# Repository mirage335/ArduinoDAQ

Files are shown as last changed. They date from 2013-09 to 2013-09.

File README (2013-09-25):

Copyright (C) 2013 mirage335
See the end of the file for license conditions.
See license.txt for USB_DAQ license conditions.

__Usage__
High-precision, low sample rate (<3kHz), DC coupled USB analog converter. Essentially a "sound card" suitable for biosignal applications (EEG), digital radios, optical sensors, hobby electronics, and other high dynamic range measurements.

BNC Connector accepts +/-8Vin. USB outputs the value according to a sample rate and format specified in firmware, by default, 100Hz @ S32_LE. LED indicator idenfities healthy startup and input overload.

__Firmware__
In the arduino IDE, set Tools --> Board --> Arduino Leonardo . Using an AVR programmer (eg. https://www.sparkfun.com/products/9825 ), either upload the leonardo bootloader or the sketch. Uploading the bootloader allows programming and serial debugging directly over USB.

__Design__
The LTC2440's input range includes floating voltages from 0.5*Vcc to -0.5Vcc. However, ESD protection circuitry rejects inputs referenced to, and below, other grounds on the chip. Carefully designed low-noise biasing circuitry negates this problem.

Board layout is critical. Neighboring digital cirucits introudce high-amplitude high-frequency noise, which is then subject to stray rectification in analog circuits. Further, the LTC2440's switched capacitor inputs introduce high frequency noise, requiring immediate decoupling.

Firmware includes code for sharp, highly efficient IIR low pass filtering. High-frequency noise may be greatly reduced with little effect on the passband.

USA companies provide all parts in these schematics.

__Safety__
USB ports are typically unfused (despite specifications to the contrary). Better to preform smoke testing with a USB wall charger, rather than an expensive computer.

Device does not offer line isolation.

_Testing_
This particular version improves noise problems encountered with the previous version. A previous version was operational, 

__Copyright__
This file is part of USB_DAQ.

USB_DAQ is free software: you can redistribute it and/or modify
it under the terms of the GNU General Public License as published by
the Free Software Foundation, either version 3 of the License, or
(at your option) any later version.

USB_DAQ is distributed in the hope that it will be useful,
but WITHOUT ANY WARRANTY; without even the implied warranty of
MERCHANTABILITY or FITNESS FOR A PARTICULAR PURPOSE.  See the
GNU General Public License for more details.

You should have received a copy of the GNU General Public License
along with USB_DAQ.  If not, see <http://www.gnu.org/licenses/>.

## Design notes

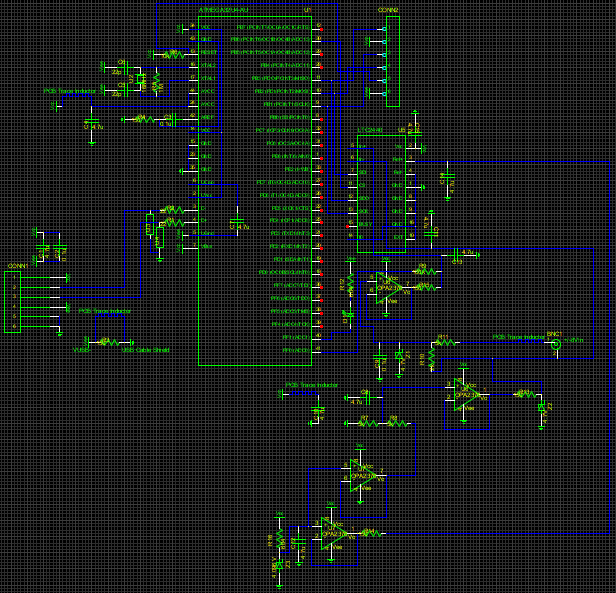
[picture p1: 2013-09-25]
USB_DAQ.sch.png

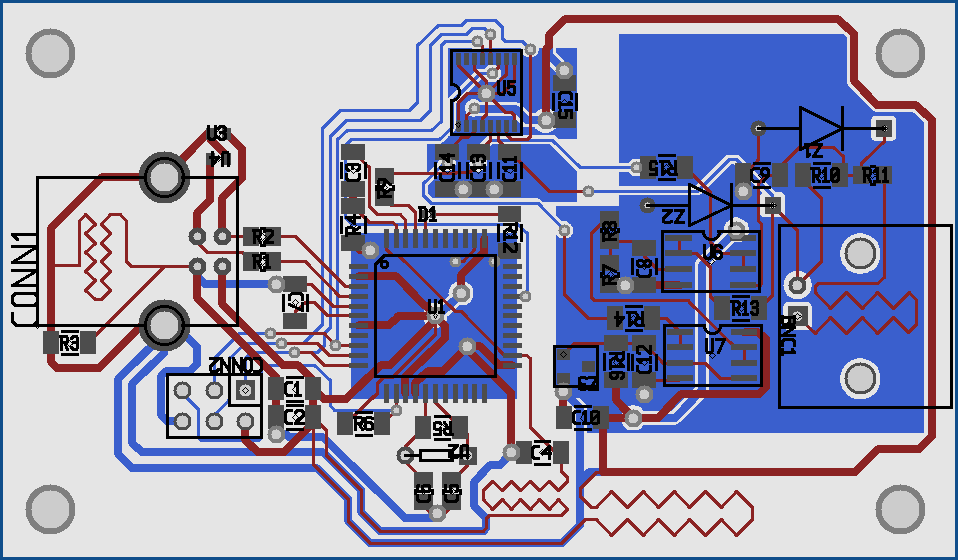
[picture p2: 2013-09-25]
USB_DAQ.pcb.png

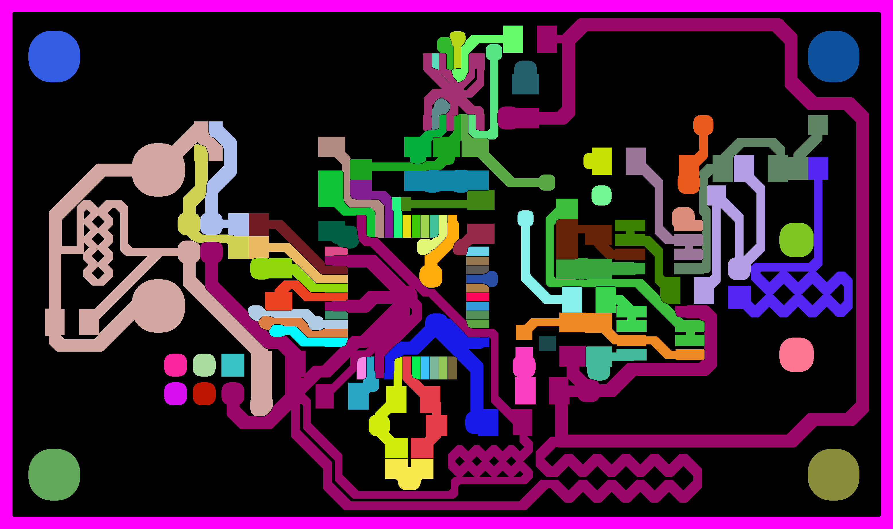
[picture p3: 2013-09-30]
hacdcCNC/USB_DAQ/outp7_traced.png

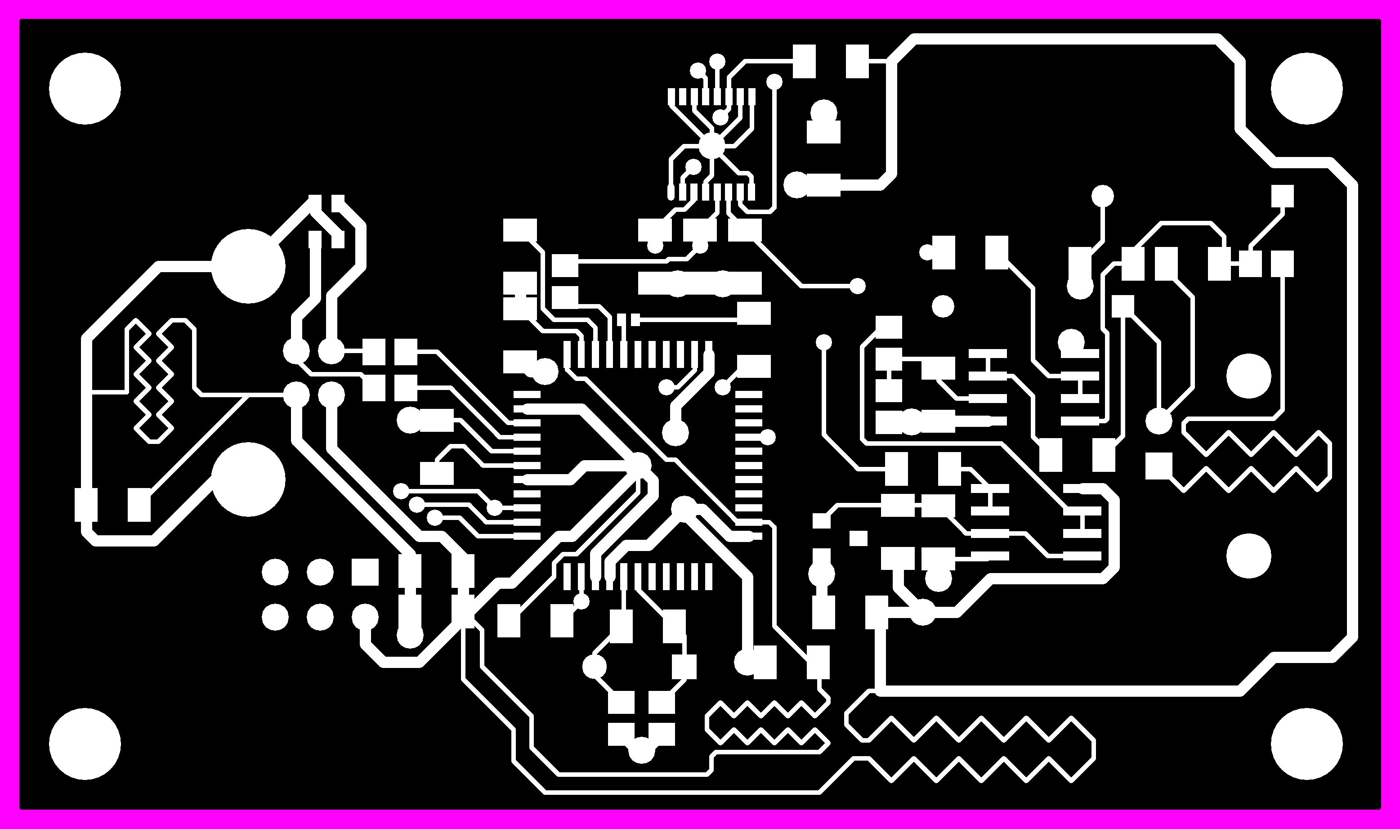
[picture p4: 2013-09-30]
hacdcCNC/USB_DAQ/outp5_masked.png

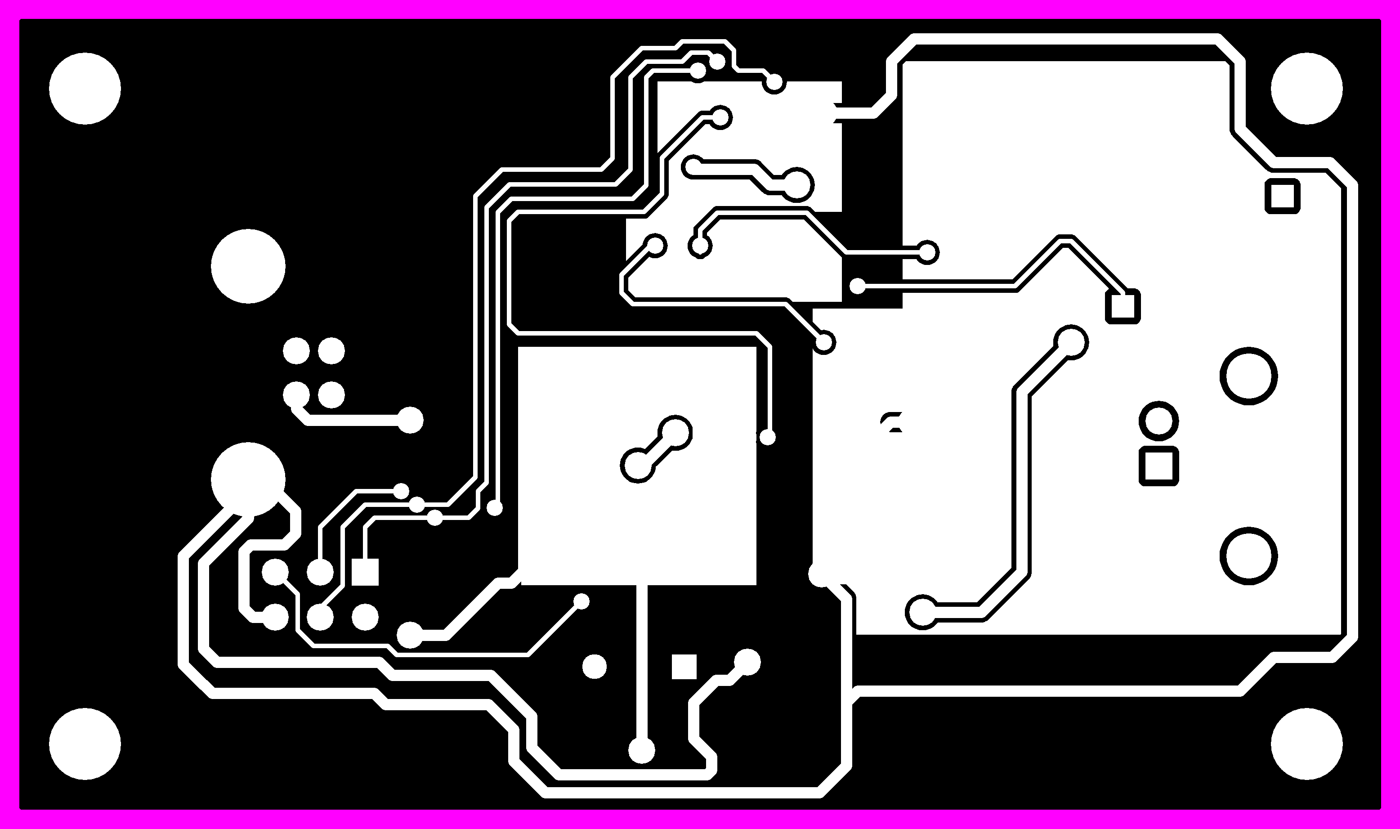
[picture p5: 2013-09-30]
hacdcCNC/USB_DAQ/outp4_masked.png

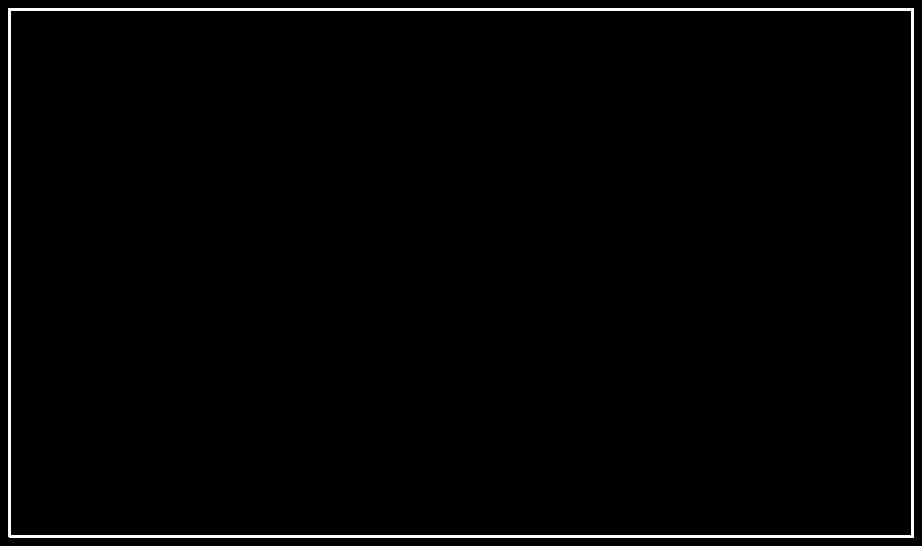
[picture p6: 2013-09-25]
hacdcCNC/USB_DAQ/outp2_original_outline.png

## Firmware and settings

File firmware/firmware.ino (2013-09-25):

/*
The MIT License (MIT)

Copyright (c) 2013 mirage335

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
THE SOFTWARE IS PROVIDED "AS IS", WITHOUT WARRANTY OF ANY KIND, EXPRESS OR
IMPLIED, INCLUDING BUT NOT LIMITED TO THE WARRANTIES OF MERCHANTABILITY,
FITNESS FOR A PARTICULAR PURPOSE AND NONINFRINGEMENT. IN NO EVENT SHALL THE
AUTHORS OR COPYRIGHT HOLDERS BE LIABLE FOR ANY CLAIM, DAMAGES OR OTHER
LIABILITY, WHETHER IN AN ACTION OF CONTRACT, TORT OR OTHERWISE, ARISING FROM,
OUT OF OR IN CONNECTION WITH THE SOFTWARE OR THE USE OR OTHER DEALINGS IN
THE SOFTWARE.
*/

/*
http://mirage335-site.dyndns.org
*/

/*
Credits:
Original example, "Interface between Arduino DM board and Linear Tech LTC2440 24-bit ADC Nov. 12 2010 John Beale" by John Beale, found at http://dangerousprototypes.com/forum/viewtopic.php?f=2&t=4247 .
Interrupt code based on example at http://www.engblaze.com/microcontroller-tutorial-avr-and-arduino-timer-interrupts/ .
Binary union based on example at http://forum.arduino.cc/index.php?topic=112597.0 .
No licenses were found with these examples. Public domain or fair use assumed.
*/

/*
Arduino DAQ Firmware
Emits samples in S32_LE format over USB Serial (ie. /dev/tty?) at the rate specificied by the sampleRate variable. Up to 3000 samples/sec has been successfully tested.

Default 100Hz sample rate, suitable for EEG pickup.

Unix machines can process this data with the following commands, among others:
stty -F /dev/ttyACM0 raw ; echo -n "" > /dev/ttyACM0 ; timeout 10 cat /dev/ttyACM0 > test ; wc -c test
stty -F /dev/ttyACM0 raw ; echo -n "" > /dev/ttyACM0 ; cat /dev/ttyACM0 | aplay -f S32_LE
stty -F /dev/ttyACM0 raw ; echo -n "" > /dev/ttyACM0 ; hexdump /dev/ttyACM0
*/

//SPI and interrupt libraries.
#include <SPI.h>
#include <avr/io.h>
#include <avr/interrupt.h>

//#define debug

//Macro function for low pass filter.
//Overuse can cause data and precision loss, especially with non-float variables.
#define lowPass(newValue, filteredValue, inertiaFloat)                            \
  filteredValue = filteredValue + (inertiaFloat * (newValue - filteredValue));

//Automatically cascades low pass filters, returning the final value as arrayName[filterLoop] .
//The arrayName is not important, however, the array must retain values from one cycle to the next (ie. static).
#define highOrderLowPass(newValue, inertiaFloat, filterOrder, arrayName)          \
  static float arrayName[(filterOrder+1)];                                        \
  arrayName[0] = newValue;                                                        \
  static int filterLoop;                                                          \
  for (filterLoop=0; filterLoop < filterOrder; filterLoop++)                      \
    lowPass(arrayName[filterLoop], arrayName[filterLoop+1], inertiaFloat);

typedef union {
  long longValue;
  byte binary[4];
} binaryLong;

//*****CONFIG*****

//Maximum sample rate is less than the LTC2440 conversion rate, defined by the oversampling ratio, set by the speedBits variable. Faster speedBits settings lead to increased noise and loss of built-in low-pass filter (anti-aliasing) characteristics. See Table 3 in the LTC2440 datasheet.
const int sampleRate = 100+1;                         //Desired sample rate in Hz. Test with stty -F /dev/ttyACM0 raw ; echo -n "" > /dev/ttyACM0 ; timeout 10 cat /dev/ttyACM0 > test ; wc -c test .
const int speedBits=0b0110;                           //Oversample ratio, determines LTC2440 bandwidth and maximum sampling rate. See datasheet Tabel 3. {0b0001 = 3.52kHz, 0b0010=1.76kHz, 0b0101=220Hz, 0b0110=110Hz, 0b1111=6.875Hz}

//Maximizes IIR low-pass anti-alias filtering.
//WARNING: Extremely high filter orders (>300) will consume too much RAM, and may break bootloaders.
const int filterOrder = (2750/sampleRate*5)%300;    //Autocalculates IIR filter maximum order up to 300.
//const int filterOrder = 300;                      //Only use for sampling rates < 50Hz.

const byte slaveSelectPin = 10;  // digital pin 10 for /CS
const int led = A4;

//*****CONFIG*****

const int convertSpeed = 0b10000000 | speedBits<<3;

//Global vairables allow interrupt preemption.
float volts = 0;
#ifdef debug
int millisOffset;
unsigned long sampleCount = 0;
#endif

void setup() {
    Serial.begin(115200);  // Maybe a lot faster over native USB.
    
    //Initiates first conversion cycle.
    pinMode (slaveSelectPin, OUTPUT);
    digitalWrite(slaveSelectPin,LOW);   // chip select is active low
    digitalWrite(slaveSelectPin,HIGH);
    
    //Configure SPI.
    SPI.begin();                          // initialize SPI, covering MOSI,MISO,SCK signals
    SPI.setBitOrder(MSBFIRST);            // data is clocked in MSB first
    SPI.setDataMode(SPI_MODE0);           // SCLK idle low (CPOL=0), MOSI read on rising edge (CPHI=0)
    SPI.setClockDivider(SPI_CLOCK_DIV2);  //8MHz clock. 250000 32bit samples/sec may be read at this rate.
    
    //Startup LED indicator.
    for (int i=0; i<=10; i++) {
      delay(100);
      digitalWrite(led, HIGH);
      delay(100);
      digitalWrite(led, LOW);
    }
    
    //Configure interrupt handler. This provides preemption and an accurate sample rate.
    // initialize Timer1
    cli();          // disable global interrupts
    TCCR1A = 0;     // set entire TCCR1A register to 0
    TCCR1B = 0;     // same for TCCR1B
    // set compare match register to desired timer count:
    OCR1A = (int)(16000000/8/sampleRate); //Counter setup.
    TCCR1B |= (1 << WGM12);               // turn on CTC mode
    TCCR1B |= (1 << CS11);
    TIMSK1 |= (1 << OCIE1A);              // enable timer compare interrupt:
    sei();                                // enable global interrupts:
    
    #ifdef debug
    millisOffset = millis();
    #endif
}

//Non critical tasks. Preempted by interrrupt handler.
void loop()
{
  #ifdef debug
  //Catches some underruns. Disable in production, to prevent false-positive due to eventual overflow.
  if (sampleCount <  sampleRate * 0.99 * (millis() - millisOffset) / 1000) {
    digitalWrite(led, HIGH);
  }
  #endif
  
  //Clipping diagnostic LED.
  if (abs(volts) > 2.45)
    digitalWrite(led, HIGH);
  else
    digitalWrite(led, LOW);
  
  delay(150);
}

//Critical path. Sample, process, and transmit data.
ISR(TIMER1_COMPA_vect)
{
  //LTC2440 SPI data acqusition cycle.
  static long b3;
  static long b2;
  static long b1;
  static long b0;
  digitalWrite(slaveSelectPin,LOW);   // take the SS pin low to select the chip
  delayMicroseconds(1);              // probably not needed, only need 25 nsec delay
  b3 = SPI.transfer(convertSpeed);   // B3
  b2 = SPI.transfer(0x00);           // B2
  b1 = SPI.transfer(0x00);           // B1
  b0 = SPI.transfer(0x00);           // B0
  // take the SS pin high to de-select the chip:
  digitalWrite(slaveSelectPin,HIGH);  //Next conversion cycle begins here.
  static long in = 0;         // incoming serial 32-bit word
  in = b3<<8;
  in |= b2;
  in = in<<8;
  in |= b1;
  in = in<<8;
  in |= b0;
  in &= 0x1FFFFFFF; // force high three bits to zero
  in = in>>5;   // truncate lowest 5 bits
  
  //Conversion to accurate voltage.
  volts = (in * (0.2980232594) * 0.000001);
  if (volts > (2.5))
    volts=((5)-volts)*(-1);  //Polarity correction.
  
  //IIR low pass filter augments LTC2440 built-in anti-alias filter, particularly at lower oversample rates (higher conversion rates).
  highOrderLowPass(volts, (float)0.45, filterOrder, specificVolts);
  
  //Human readable format.
  //Serial.println("");
  //Serial.println((float)volts,6);                       //Raw.
  //Serial.println((float)(specificVolts[filterLoop]),6); //Filtered.
  
  //Prepare value for binary readout.
  static binaryLong convertableMicroVolts;
  convertableMicroVolts.longValue = specificVolts[filterLoop] * 1000000;
  
  //Optional gain. Drops dynamic range..
  //convertableMicroVolts.longValue *= (long)1000000;
  
  //Compatible with aplay -f S32_LE .
  Serial.write(convertableMicroVolts.binary,4);
  
  #ifdef debug
  sampleCount++;
  #endif
}

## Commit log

2013-09-26 Pullup resistor on SCK to prevent spurious LTC2440 response during ISP programming.
    [USB_DAQ.sch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]
2013-09-30 Pullup resistor moved from SCK to CS.
    [USB_DAQ.sch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]
2013-09-30 Improved AVR power/ground path.
